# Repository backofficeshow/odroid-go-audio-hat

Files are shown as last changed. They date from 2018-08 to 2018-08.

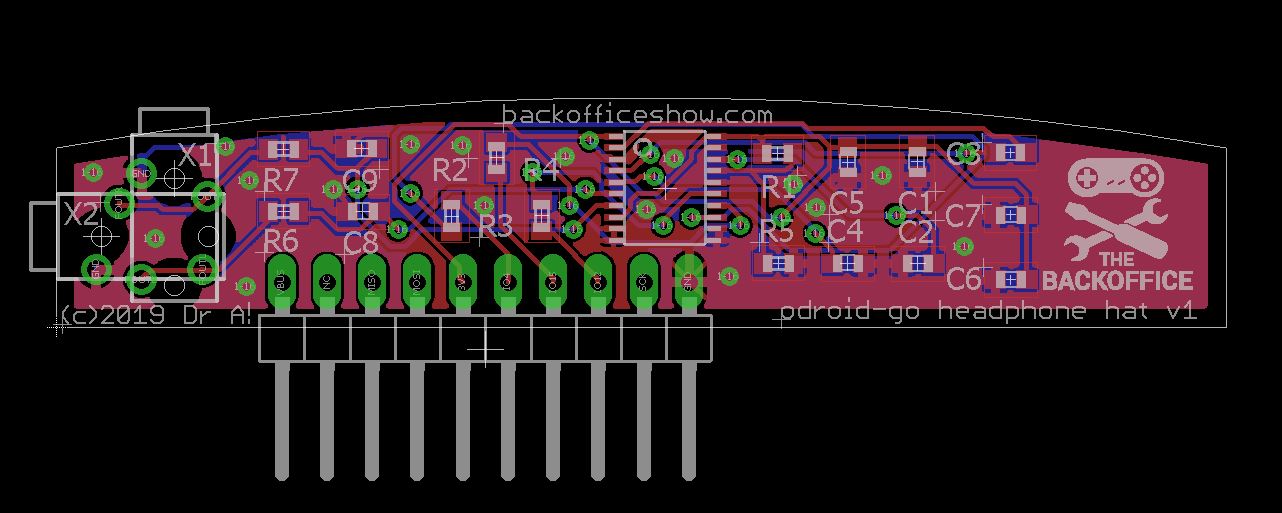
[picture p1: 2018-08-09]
odroid-go audio hat v1.jpg

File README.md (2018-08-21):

# odroid-go-audio-hat
An I2S Audio Hat for stereo sound from the odroid-go

UPDATE: The live build stream! https://youtu.be/j9-wCR7noaQ

1) A Manual Mod Was Made:

https://youtu.be/pp_DPHiUhcc

2) A SPI option conceived and failed:

https://youtu.be/Ehr8WgxajMo

https://www.youtube.com/watch?v=8DnR3sBm568

3) This forum thread provided the answers:

https://forum.odroid.com/viewtopic.php?f=158&t=31853&p=231227#p231227

crashoverride knows all the magic gpio runes!

4) The results are this archive!

https://www.youtube.com/watch?v=rQte53dfJiA

https://www.youtube.com/backofficeshow

Come chat with me on discord https://discord.gg/6UB4Zj7

Useful Links

PCM5102 Datasheet:

http://www.ti.com/lit/ds/slas764b/slas764b.pdf

Odroid-go Overview:

https://www.hardkernel.com/main/products/prdt_info.php?g_code=G152875062626

Odroid-go IO Information:

https://wiki.odroid.com/odroid_go/odroid_go#odroid-go_header_p2_description

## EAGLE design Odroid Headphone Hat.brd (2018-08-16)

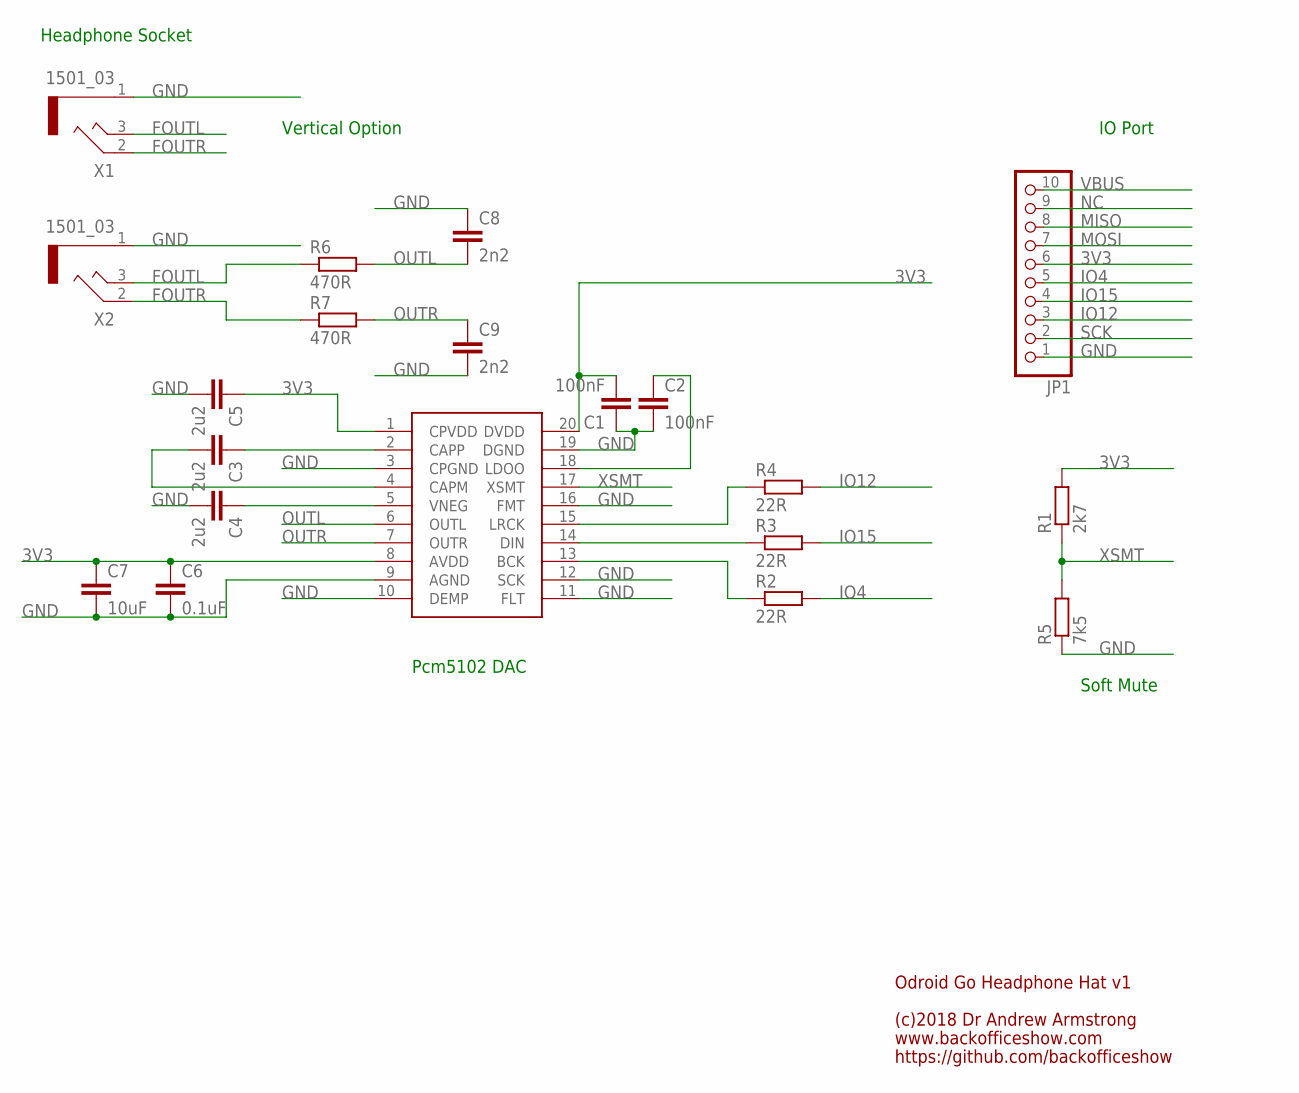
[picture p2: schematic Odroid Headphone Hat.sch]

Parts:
C1, C2: 100nF; C0603
C3, C4, C5: 2u2; C0603
C6: 0.1uF; C0603
C7: 10uF; C0603
C8, C9: 2n2; C0603
JP1: PINHD-1X10/90; 1X10/90
R1: 2k7; R0603
R2, R3, R4: 22R; R0603
R5: 7k5; R0603
R6, R7: 470R; R0603
U$1: PCM5102; TSSOP20
X1, X2: 1501_03

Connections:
3V3: C1.2, C5.1, C6.1, C7.1, JP1.6, R1.2, U$1.1 (CPVDD), U$1.8 (AVDD), U$1.20 (DVDD)
FOUTL: R6.1, X1.3, X2.3
FOUTR: R7.1, X1.2, X2.2
GND: C1.1, C2.2, C4.2, C5.2, C6.2, C7.2, C8.1, C9.2, JP1.1, R5.1, U$1.3 (CPGND), U$1.9 (AGND), U$1.10 (DEMP), U$1.11 (FLT), U$1.12 (SCK), U$1.16 (FMT), U$1.19 (DGND), X1.1, X2.1
IO4: JP1.5, R2.2
IO12: JP1.3, R4.2
IO15: JP1.4, R3.2
MISO: JP1.8
MOSI: JP1.7
unnamed: R2.1, U$1.13 (BCK)
unnamed: R3.1, U$1.14 (DIN)
unnamed: R4.1, U$1.15 (LRCK)
unnamed: C2.1, U$1.18 (LDOO)
unnamed: C3.1, U$1.2 (CAPP)
unnamed: C3.2, U$1.4 (CAPM)
unnamed: C4.1, U$1.5 (VNEG)
NC: JP1.9
OUTL: C8.2, R6.2, U$1.6 (OUTL)
OUTR: C9.1, R7.2, U$1.7 (OUTR)
SCK: JP1.2
VBUS: JP1.10
XSMT: R1.1, R5.2, U$1.17 (XSMT)

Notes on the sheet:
Odroid Go Headphone Hat v1
(c)2018 Dr Andrew Armstrong
www.backofficeshow.com
https://github.com/backofficeshow
Soft Mute
IO Port
Pcm5102 DAC
Headphone Socket
Vertical Option

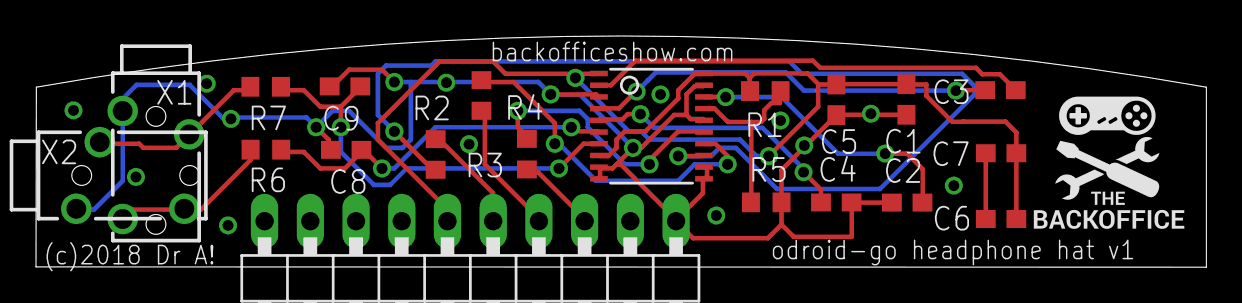
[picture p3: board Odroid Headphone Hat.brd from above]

Board: 2 copper layers, 65.0 x 12.8 mm, 20 parts (0 on the bottom side), 17 nets.

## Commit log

2018-08-09 v1 Upload of the hat schematic and board
    Uploaded in eagle format, ready to be fabricated and tested
    [Odroid Headphone Hat.brd, Odroid Headphone Hat.sch]
2018-08-10 A few tweeks
    [Odroid Headphone Hat.brd, Odroid Headphone Hat.sch]
2018-08-10 Vias Tented ready for print
    [Odroid Headphone Hat.brd]
2018-08-10 Just a dimensional tweek
    [Odroid Headphone Hat.brd]
2018-08-16 tweeks to get working - no headphone mod yet
    [Odroid Headphone Hat.brd, Odroid Headphone Hat.sch]
